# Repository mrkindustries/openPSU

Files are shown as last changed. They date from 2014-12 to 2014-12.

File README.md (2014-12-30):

openPSU
=============

## Open source lab power supply unit

openPSU is a **0-30V, 0-3A** linear power supply unit. There are similar schematics and layout files all over the internet, but few of them come with proper design files and project documentation.

A linear power supply has less HF noise than a switching supply and has a better response to quick load changes. And most important, it is so simple that you can repair it yourself. I've been using the same one for over 10 years.

It is desgned to be connected to a transformer, fine/coarse/current pots and those cheap 7 digit displays. An all-digital board could be stacked on top to provide programmable control and datalogging.

## Schematic
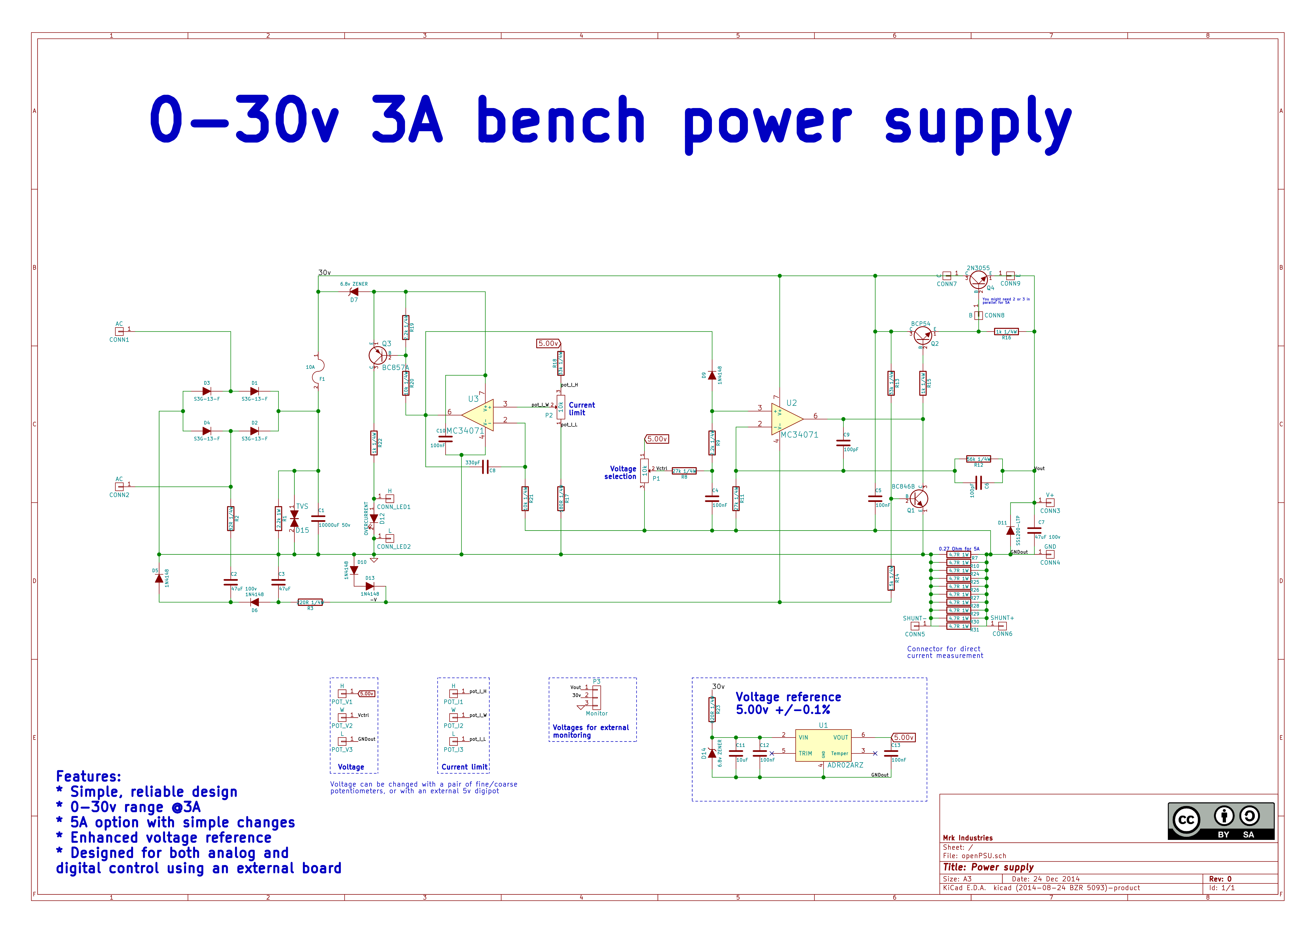
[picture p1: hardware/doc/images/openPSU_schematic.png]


## 3D views
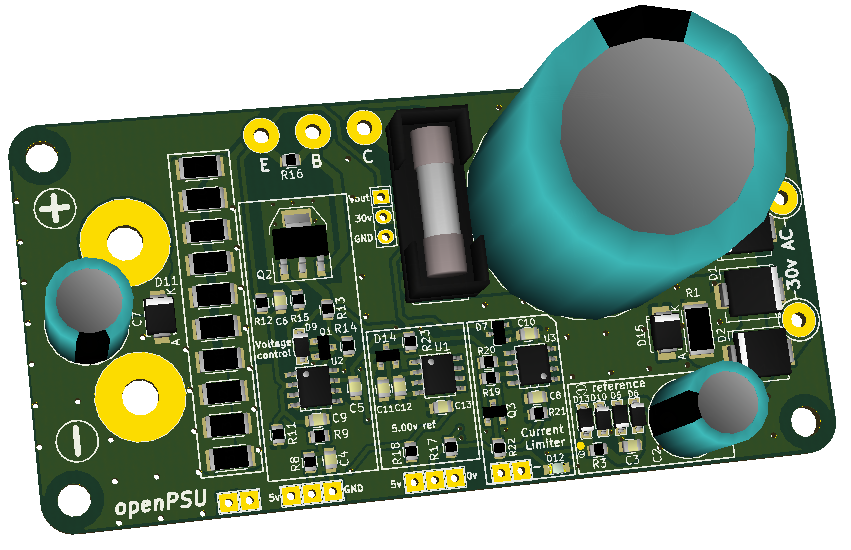
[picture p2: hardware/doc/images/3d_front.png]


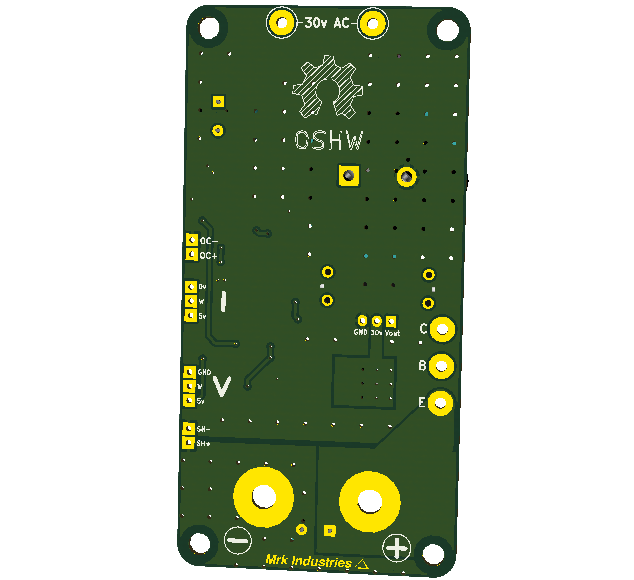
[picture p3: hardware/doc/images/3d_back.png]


This board was designed using kicad, you can find the CAD files in the /hardware/design folder
http://www.kicad-pcb.org

Download the schematic

[openPSU_schematic.pdf](/hardware/doc/openPSU_schematic.pdf?raw=true)

Order the BOM directly from Digikey, no parts uploading required.

http://www.digikey.com/short/747hq8

**Warning:** untested until the first prototype arrives

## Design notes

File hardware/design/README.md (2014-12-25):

# Notes

* Designed using kicad version 2014-08-24 BZR 5093. Older versions (like 2013-ish) will open the schematic but could fail to load the kicad-pcb file.

* 3D models come from http://smisioto.no-ip.org/elettronica/kicad/kicad.htm

* BOM was chosen based on digikey stock, automatically generated by a kicad python script

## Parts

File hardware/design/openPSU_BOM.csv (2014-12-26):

Source: | /home/marcos/electronica/Mrk industries/devs_internos/openPSU/hardware/design/openPSU.sch
Date: | Fri 26 Dec 2014 03:28:25 PM ART
Tool: | Eeschema (2014-08-24 BZR 5093)-product
Component Count: | 85
Individual Components:
Item | Qty | Reference(s) | Value | LibPart | Footprint | Datasheet | mfg#
 |  | C1 | 10000uF 50v | openPSU-cache:C |  | Capacitors_ThroughHole:Capacitor30x51RM10 |  | SLPX103M050E7P3
 |  | C10 | 100nF | openPSU-cache:C |  | Capacitors_SMD:C_0805
 |  | C11 | 10uF | openPSU-cache:C |  | Capacitors_SMD:C_0805 |  | GRM21BR71A106MA73L
 |  | C12 | 100nF | openPSU-cache:C |  | Capacitors_SMD:C_0805
 |  | C13 | 100nF | openPSU-cache:C |  | Capacitors_SMD:C_0805
 |  | C2 | 47uF 100v | openPSU-cache:C |  | Capacitors_ThroughHole:Capacitor10x16RM5 |  | UPW2A470MPD
 |  | C3 | 47uF | openPSU-cache:C |  | Capacitors_SMD:C_0805 |  | CL21A476MQCLRNC
 |  | C4 | 100nF | openPSU-cache:C |  | Capacitors_SMD:C_0805 |  | CL21B104KBCNNNC
 |  | C5 | 100nF | openPSU-cache:C |  | Capacitors_SMD:C_0805
 |  | C6 | 100pF | openPSU-cache:C |  | Capacitors_SMD:C_0805 |  | C0805C101J5GACTU
 |  | C7 | 47uF 100v | openPSU-cache:C |  | Capacitors_ThroughHole:Capacitor10x16RM5 |  | UPW2A470MPD
 |  | C8 | 330pF | openPSU-cache:C |  | Capacitors_SMD:C_0805 |  | C0805C331J5GACTU
 |  | C9 | 100pF | openPSU-cache:C |  | Capacitors_SMD:C_0805 |  | C0805C101J5GACTU
 |  | CONN1 | AC | openPSU-cache:CONN_01X01 |  | Wire_Pads:SolderWirePad_single_2mmDrill
 |  | CONN2 | AC | openPSU-cache:CONN_01X01 |  | Wire_Pads:SolderWirePad_single_2mmDrill
 |  | CONN3 | V+ | openPSU-cache:CONN_01X01 |  | Wire_Pads:SolderWirePad_single_2-5mmDrill
 |  | CONN4 | GND | openPSU-cache:CONN_01X01 |  | Wire_Pads:SolderWirePad_single_2-5mmDrill
 |  | CONN5 | SHUNT- | openPSU-cache:CONN_01X01 |  | Socket_Strips:Socket_Strip_Straight_1x01
 |  | CONN6 | SHUNT+ | openPSU-cache:CONN_01X01 |  | Socket_Strips:Socket_Strip_Straight_1x01
 |  | CONN7 | C | openPSU-cache:CONN_01X01 |  | Wire_Pads:SolderWirePad_single_2mmDrill
 |  | CONN8 | B | openPSU-cache:CONN_01X01 |  | Wire_Pads:SolderWirePad_single_2mmDrill
 |  | CONN9 | E | openPSU-cache:CONN_01X01 |  | Wire_Pads:SolderWirePad_single_2mmDrill
 |  | CONN_LED1 | H | openPSU-cache:CONN_01X01 |  | Socket_Strips:Socket_Strip_Straight_1x01
 |  | CONN_LED2 | L | openPSU-cache:CONN_01X01 |  | Socket_Strips:Socket_Strip_Straight_1x01
 |  | D1 | S3G-13-F | openPSU-cache:DIODE |  | Diodes_SMD:Diode-SMC_Standard |  | S3G-13-F
 |  | D10 | 1N4148 | openPSU-cache:DIODE |  | Mrk:SOD-123 |  | 1N4148W-7-F
 |  | D11 | SS1200-LTP | openPSU-cache:DIODE |  | Diodes_SMD:Diode-SMA_Standard |  | SS1200-LTP
 |  | D12 | OVERCURRENT | openPSU-cache:LED |  | LEDs:LED-0805 |  | LH R974-LP-1
 |  | D13 | 1N4148 | openPSU-cache:DIODE |  | Mrk:SOD-123 |  | 1N4148W-7-F
 |  | D14 | 6.8v ZENER | openPSU-cache:ZENER |  | SMD_Packages:SOT-23 |  | BZX84C6V8LT1G
 |  | D15 | TVS | openPSU-cache:TVS |  | Diodes_SMD:Diode-SMB_Standard |  | 1SMB30AT3G
 |  | D2 | S3G-13-F | openPSU-cache:DIODE |  | Diodes_SMD:Diode-SMC_Standard |  | S3G-13-F
 |  | D3 | S3G-13-F | openPSU-cache:DIODE |  | Diodes_SMD:Diode-SMC_Standard |  | S3G-13-F
 |  | D4 | S3G-13-F | openPSU-cache:DIODE |  | Diodes_SMD:Diode-SMC_Standard |  | S3G-13-F
 |  | D5 | 1N4148 | openPSU-cache:DIODE |  | Mrk:SOD-123 |  | 1N4148W-7-F
 |  | D6 | 1N4148 | openPSU-cache:DIODE |  | Mrk:SOD-123 |  | 1N4148W-7-F
 |  | D7 | 6.8v ZENER | openPSU-cache:ZENER |  | Transistors_SMD:sot23 |  | BZX84C6V8LT1G
 |  | D8 | BLOWN | openPSU-cache:LED |  | LEDs:LED-0805
 |  | D9 | 1N4148 | openPSU-cache:DIODE |  | Mrk:SOD-123
 |  | F1 | 10A | openPSU-cache:FUSE |  | Fuse_Holders_and_Fuses:Fuseholder5x20_horiz_open_universal_Type-III |  | 01110501Z
 |  | P1 | 10k | openPSU-cache:POT
 |  | P2 | 10k | openPSU-cache:POT
 |  | P3 | Monitor | openPSU-cache:CONN_01X03 |  | Socket_Strips:Socket_Strip_Straight_1x03
 |  | POT_I1 | H | openPSU-cache:CONN_01X01 |  | Socket_Strips:Socket_Strip_Straight_1x01
 |  | POT_I2 | W | openPSU-cache:CONN_01X01 |  | Socket_Strips:Socket_Strip_Straight_1x01
 |  | POT_I3 | L | openPSU-cache:CONN_01X01 |  | Socket_Strips:Socket_Strip_Straight_1x01
 |  | POT_V1 | H | openPSU-cache:CONN_01X01 |  | Socket_Strips:Socket_Strip_Straight_1x01
 |  | POT_V2 | W | openPSU-cache:CONN_01X01 |  | Socket_Strips:Socket_Strip_Straight_1x01
 |  | POT_V3 | L | openPSU-cache:CONN_01X01 |  | Socket_Strips:Socket_Strip_Straight_1x01
 |  | Q1 | BC846B | openPSU-cache:NPN |  | SMD_Packages:SOT-23 |  | BC846B,215
 |  | Q2 | BCP54 | openPSU-cache:NPN |  | SMD_Packages:SOT-223 |  | BCP54
 |  | Q3 | BC857A | openPSU-cache:PNP |  | SMD_Packages:SOT-23 |  | BC857A-TP
 |  | Q4 | 2N3055 | openPSU-cache:NPN |  | Discret:TO3 |  | 2N3055G
 |  | R1 | 2.2k 1W | openPSU-cache:R |  | Resistors_SMD:R_2512 |  | MCR100JZHJ222
 |  | R10 | 4.7R 1W | openPSU-cache:R |  | Resistors_SMD:R_2010 |  | CRM2010-JW-4R7ELF
 |  | R11 | 27k 1/4W | openPSU-cache:R |  | Resistors_SMD:R_0805 |  | RC0805FR-0727KL
 |  | R12 | 56k 1/4W | openPSU-cache:R |  | Resistors_SMD:R_0805 |  | RC0805FR-0756KL
 |  | R13 | 33k 1/4W | openPSU-cache:R |  | Resistors_SMD:R_0805 |  | RC0805FR-0733KL
 |  | R14 | 1.5k 1/4W | openPSU-cache:R |  | Resistors_SMD:R_0805 |  | RC0805FR-071K5L
 |  | R15 | 1k 1/4W | openPSU-cache:R |  | Resistors_SMD:R_0805 |  | RC0805FR-071KL
 |  | R16 | 1k 1/4W | openPSU-cache:R |  | Resistors_SMD:R_0805 |  | RC0805FR-071KL
 |  | R17 | 180R 1/4W | openPSU-cache:R |  | Resistors_SMD:R_0805 |  | RC0805FR-07180RL
 |  | R18 | 33k 1/4W | openPSU-cache:R |  | Resistors_SMD:R_0805 |  | RC0805FR-0733KL
 |  | R19 | 2.2k 1/4W | openPSU-cache:R |  | Resistors_SMD:R_0805 |  | RC0805FR-072K2L
 |  | R2 | 82R 1/4W | openPSU-cache:R |  | Resistors_SMD:R_0805 |  | RC0805FR-0782RL
 |  | R20 | 10k 1/4W | openPSU-cache:R |  | Resistors_SMD:R_0805 |  | RC0805FR-0710KL
 |  | R21 | 10k 1/4W | openPSU-cache:R |  | Resistors_SMD:R_0805 |  | RC0805FR-0710KL
 |  | R22 | 1k 1/4W | openPSU-cache:R |  | Resistors_SMD:R_0805
 |  | R23 | 820R 1/4W | openPSU-cache:R |  | Resistors_SMD:R_0805 |  | RC0805FR-07820RL
 |  | R24 | 4.7R 1W | openPSU-cache:R |  | Resistors_SMD:R_2010 |  | CRM2010-JW-4R7ELF
 |  | R25 | 4.7R 1W | openPSU-cache:R |  | Resistors_SMD:R_2010 |  | CRM2010-JW-4R7ELF
 |  | R26 | 4.7R 1W | openPSU-cache:R |  | Resistors_SMD:R_2010 |  | CRM2010-JW-4R7ELF
 |  | R27 | 4.7R 1W | openPSU-cache:R |  | Resistors_SMD:R_2010 |  | CRM2010-JW-4R7ELF
 |  | R28 | 4.7R 1W | openPSU-cache:R |  | Resistors_SMD:R_2010 |  | CRM2010-JW-4R7ELF
 |  | R29 | 4.7R 1W | openPSU-cache:R |  | Resistors_SMD:R_2010 |  | CRM2010-JW-4R7ELF
 |  | R3 | 220R 1/4W | openPSU-cache:R |  | Resistors_SMD:R_0805 |  | RC0805FR-07220RL
 |  | R30 | 4.7R 1W | openPSU-cache:R |  | Resistors_SMD:R_2010 |  | CRM2010-JW-4R7ELF
 |  | R31 | 4.7R 1W | openPSU-cache:R |  | Resistors_SMD:R_2010 |  | CRM2010-JW-4R7ELF
 |  | R4 | 10k 1/4W | openPSU-cache:R |  | Resistors_SMD:R_0805
 |  | R7 | 4.7R 1W | openPSU-cache:R |  | Resistors_ThroughHole:Resistor_Ceramic_Horizontal_L36mm-W11mm-H10mm-p45mm |  | CRM2010-JW-4R7ELF
 |  | R8 | 27k 1/4W | openPSU-cache:R |  | Resistors_SMD:R_0805 |  | RC0805FR-0727KL
 |  | R9 | 2.2k 1/4W | openPSU-cache:R |  | Resistors_SMD:R_0805 |  | RC0805FR-072K2L
 |  | U1 | ADR02ARZ | openPSU-cache:MAX874 |  | SMD_Packages:SOIC-8-W |  | ADR02ARZ-REEL7
 |  | U2 | MC34071 | openPSU-cache:TL081 |  | SMD_Packages:SOIC-8-W |  | MC34071ADG
 |  | U3 | MC34071 | openPSU-cache:TL081 |  | SMD_Packages:SOIC-8-W |  | MC34071ADG
Collated Components:
Item | Qty | Reference(s) | Value | LibPart | Footprint | Datasheet | mfg#
1 | 1 | C1 | 10000uF 50v | openPSU-cache:C | Capacitors_ThroughHole:Capacitor30x51RM10 |  | SLPX103M050E7P3
2 | 5 | C10, C12, C13, C4, C5 | 100nF | openPSU-cache:C | Capacitors_SMD:C_0805 |  | CL21B104KBCNNNC
3 | 1 | C11 | 10uF | openPSU-cache:C | Capacitors_SMD:C_0805 |  | GRM21BR71A106MA73L
4 | 2 | C2, C7 | 47uF 100v | openPSU-cache:C | Capacitors_ThroughHole:Capacitor10x16RM5 |  | UPW2A470MPD
5 | 1 | C3 | 47uF | openPSU-cache:C | Capacitors_SMD:C_0805 |  | CL21A476MQCLRNC
6 | 2 | C6, C9 | 100pF | openPSU-cache:C | Capacitors_SMD:C_0805 |  | C0805C101J5GACTU
7 | 1 | C8 | 330pF | openPSU-cache:C | Capacitors_SMD:C_0805 |  | C0805C331J5GACTU
8 | 2 | CONN1, CONN2 | AC | openPSU-cache:CONN_01X01 | Wire_Pads:SolderWirePad_single_2mmDrill
9 | 1 | CONN3 | V+ | openPSU-cache:CONN_01X01 | Wire_Pads:SolderWirePad_single_2-5mmDrill
10 | 1 | CONN4 | GND | openPSU-cache:CONN_01X01 | Wire_Pads:SolderWirePad_single_2-5mmDrill
11 | 1 | CONN5 | SHUNT- | openPSU-cache:CONN_01X01 | Socket_Strips:Socket_Strip_Straight_1x01
12 | 1 | CONN6 | SHUNT+ | openPSU-cache:CONN_01X01 | Socket_Strips:Socket_Strip_Straight_1x01
13 | 1 | CONN7 | C | openPSU-cache:CONN_01X01 | Wire_Pads:SolderWirePad_single_2mmDrill
14 | 1 | CONN8 | B | openPSU-cache:CONN_01X01 | Wire_Pads:SolderWirePad_single_2mmDrill
15 | 1 | CONN9 | E | openPSU-cache:CONN_01X01 | Wire_Pads:SolderWirePad_single_2mmDrill
16 | 3 | CONN_LED1, POT_I1, POT_V1 | H | openPSU-cache:CONN_01X01 | Socket_Strips:Socket_Strip_Straight_1x01
17 | 3 | CONN_LED2, POT_I3, POT_V3 | L | openPSU-cache:CONN_01X01 | Socket_Strips:Socket_Strip_Straight_1x01
18 | 4 | D1, D2, D3, D4 | S3G-13-F | openPSU-cache:DIODE | Diodes_SMD:Diode-SMC_Standard |  | S3G-13-F
19 | 5 | D10, D13, D5, D6, D9 | 1N4148 | openPSU-cache:DIODE | Mrk:SOD-123 |  | 1N4148W-7-F
20 | 1 | D11 | SS1200-LTP | openPSU-cache:DIODE | Diodes_SMD:Diode-SMA_Standard |  | SS1200-LTP
21 | 1 | D12 | OVERCURRENT | openPSU-cache:LED | LEDs:LED-0805 |  | LH R974-LP-1
22 | 2 | D14, D7 | 6.8v ZENER | openPSU-cache:ZENER | SMD_Packages:SOT-23 |  | BZX84C6V8LT1G
23 | 1 | D15 | TVS | openPSU-cache:TVS | Diodes_SMD:Diode-SMB_Standard |  | 1SMB30AT3G
24 | 1 | D8 | BLOWN | openPSU-cache:LED | LEDs:LED-0805
25 | 1 | F1 | 10A | openPSU-cache:FUSE | Fuse_Holders_and_Fuses:Fuseholder5x20_horiz_open_universal_Type-III |  | 01110501Z
26 | 2 | P1, P2 | 10k | openPSU-cache:POT
27 | 1 | P3 | Monitor | openPSU-cache:CONN_01X03 | Socket_Strips:Socket_Strip_Straight_1x03
28 | 2 | POT_I2, POT_V2 | W | openPSU-cache:CONN_01X01 | Socket_Strips:Socket_Strip_Straight_1x01
29 | 1 | Q1 | BC846B | openPSU-cache:NPN | SMD_Packages:SOT-23 |  | BC846B,215
30 | 1 | Q2 | BCP54 | openPSU-cache:NPN | SMD_Packages:SOT-223 |  | BCP54
31 | 1 | Q3 | BC857A | openPSU-cache:PNP | SMD_Packages:SOT-23 |  | BC857A-TP
32 | 1 | Q4 | 2N3055 | openPSU-cache:NPN | Discret:TO3 |  | 2N3055G
33 | 1 | R1 | 2.2k 1W | openPSU-cache:R | Resistors_SMD:R_2512 |  | MCR100JZHJ222
34 | 10 | R10, R24, R25, R26, R27, R28, R29, R30, R31, R7 | 4.7R 1W | openPSU-cache:R | Resistors_SMD:R_2010 |  | CRM2010-JW-4R7ELF
35 | 2 | R11, R8 | 27k 1/4W | openPSU-cache:R | Resistors_SMD:R_0805 |  | RC0805FR-0727KL
36 | 1 | R12 | 56k 1/4W | openPSU-cache:R | Resistors_SMD:R_0805 |  | RC0805FR-0756KL
37 | 2 | R13, R18 | 33k 1/4W | openPSU-cache:R | Resistors_SMD:R_0805 |  | RC0805FR-0733KL
38 | 1 | R14 | 1.5k 1/4W | openPSU-cache:R | Resistors_SMD:R_0805 |  | RC0805FR-071K5L
39 | 3 | R15, R16, R22 | 1k 1/4W | openPSU-cache:R | Resistors_SMD:R_0805 |  | RC0805FR-071KL
40 | 1 | R17 | 180R 1/4W | openPSU-cache:R | Resistors_SMD:R_0805 |  | RC0805FR-07180RL
41 | 2 | R19, R9 | 2.2k 1/4W | openPSU-cache:R | Resistors_SMD:R_0805 |  | RC0805FR-072K2L
42 | 1 | R2 | 82R 1/4W | openPSU-cache:R | Resistors_SMD:R_0805 |  | RC0805FR-0782RL
43 | 3 | R20, R21, R4 | 10k 1/4W | openPSU-cache:R | Resistors_SMD:R_0805 |  | RC0805FR-0710KL
44 | 1 | R23 | 820R 1/4W | openPSU-cache:R | Resistors_SMD:R_0805 |  | RC0805FR-07820RL
45 | 1 | R3 | 220R 1/4W | openPSU-cache:R | Resistors_SMD:R_0805 |  | RC0805FR-07220RL
46 | 1 | U1 | ADR02ARZ | openPSU-cache:MAX874 | SMD_Packages:SOIC-8-W |  | ADR02ARZ-REEL7
47 | 2 | U2, U3 | MC34071 | openPSU-cache:TL081 | SMD_Packages:SOIC-8-W |  | MC34071ADG

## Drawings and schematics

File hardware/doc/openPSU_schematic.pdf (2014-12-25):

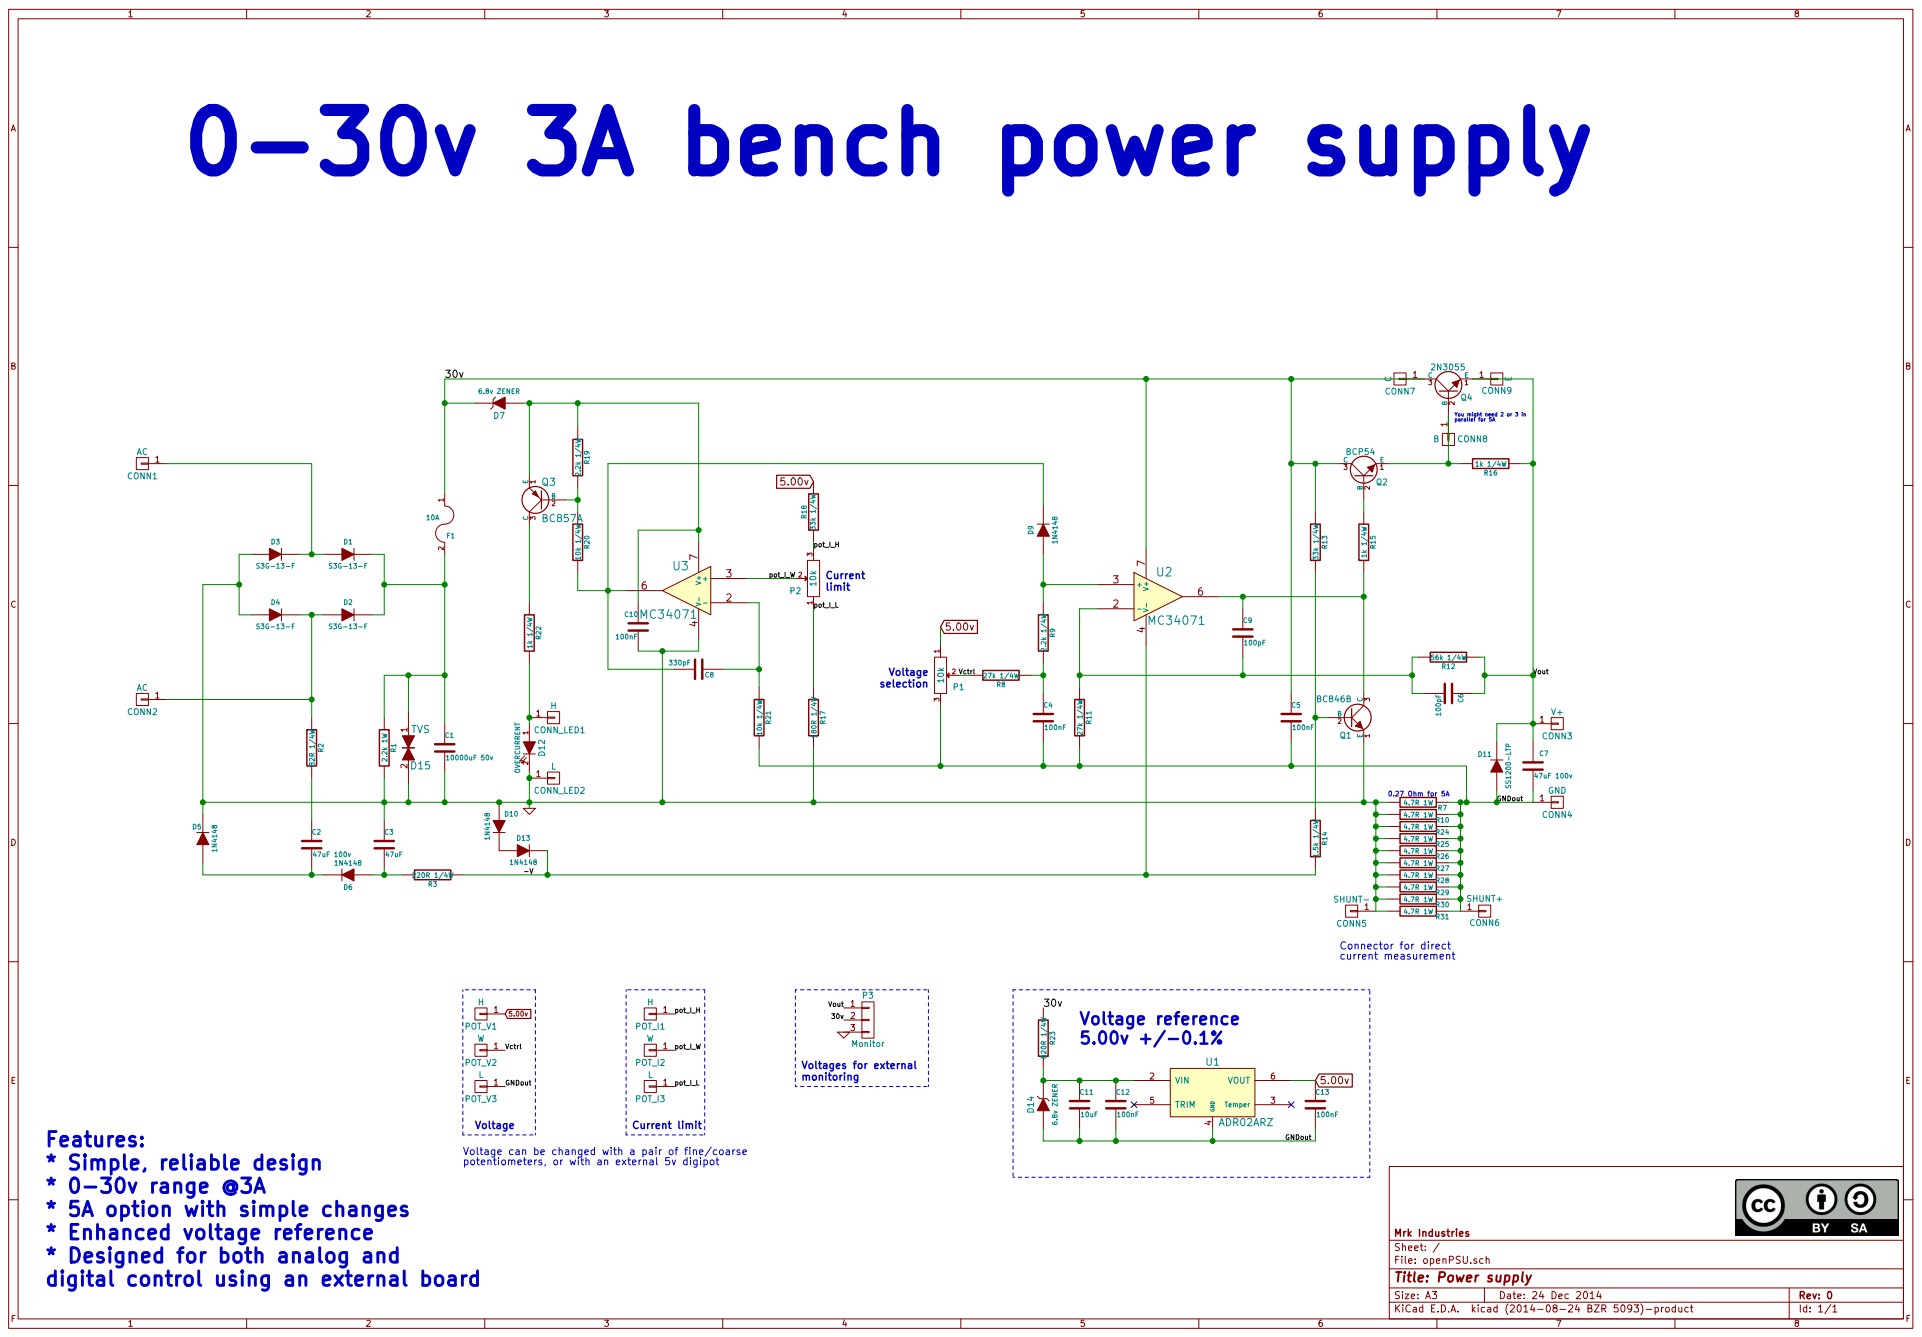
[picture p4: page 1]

You might need 2 or 3 in
parallel for 5A

0.27 Ohm for 5A

4.7R 1W | R10
4.7R 1W | R24
4.7R 1W | R25
4.7R 1W | R26
4.7R 1W | R27
4.7R 1W | R28
4.7R 1W | R29
4.7R 1W | R30

3 P3 Monitor Vout 30v Voltages for external monitoring Features:

* Simple, reliable design
* 0-30v range @3A
* 5A option with simple changes
* Enhanced voltage reference
* Designed for both analog and
digital control using an external board

File: openPSU.sch Sheet: / Mrk Industries

Id: 1/1 Title: Power supply

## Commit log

2014-12-19 Schematic mostly completed
    [fuente.sch]
2014-12-24 Schematic almost finished. Improved voltage reference, added changes according to diyfan, added fuse and changed the 10W resistor for 10 1W SMD resistors. Layout mostly complete
    [fuente.kicad_pcb, fuente.sch]
2014-12-24 Updated readme and added a couple of images
2014-12-24 Added BOM and minor changes
    [openPSU.kicad_pcb, openPSU.sch, openPSU_BOM.csv]
2014-12-24 Fixed transistors and zeners pinouts. Added the last connector so we can stack a digital board on top. It could support a display, communications, programmable voltage and datalogging. Added manufact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
    [openPSU.kicad_pcb, openPSU.sch]
2014-12-25 Readme updated with easy to access schematics
    [openPSU.sch]
2014-12-25 Added some notes for using the CAD files
2014-12-26 Created a one-click digikey BOM, enlarged output pads and minor changes. The order was rejected from iteadstudio due to the extended attributes in kicad gerber file. Its now corrected and the product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
    [openPSU.kicad_pcb, openPSU.sch, openPSU_BOM.csv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]
2014-12-30 Very minor changes
    [openPSU.kicad_pcb]
